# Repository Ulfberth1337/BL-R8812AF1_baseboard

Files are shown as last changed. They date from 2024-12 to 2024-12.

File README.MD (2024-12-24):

This is a baseboard for BL-R8812AF1 WI-FI Module.
USB and Power can be suplied by USB TYPE-C connector or by using TH Pads.
Power requirments are 5V +/- 5% and current 1A.
Baseboard got resetable fuse in order to protect power supply from short circuit and reverse polarity protection.

!!! USE AT OWN RISK !!!

UPD reverse polarity protection part will not work, I mixed up source with drain on mosfet.
The rest of the board works fine.

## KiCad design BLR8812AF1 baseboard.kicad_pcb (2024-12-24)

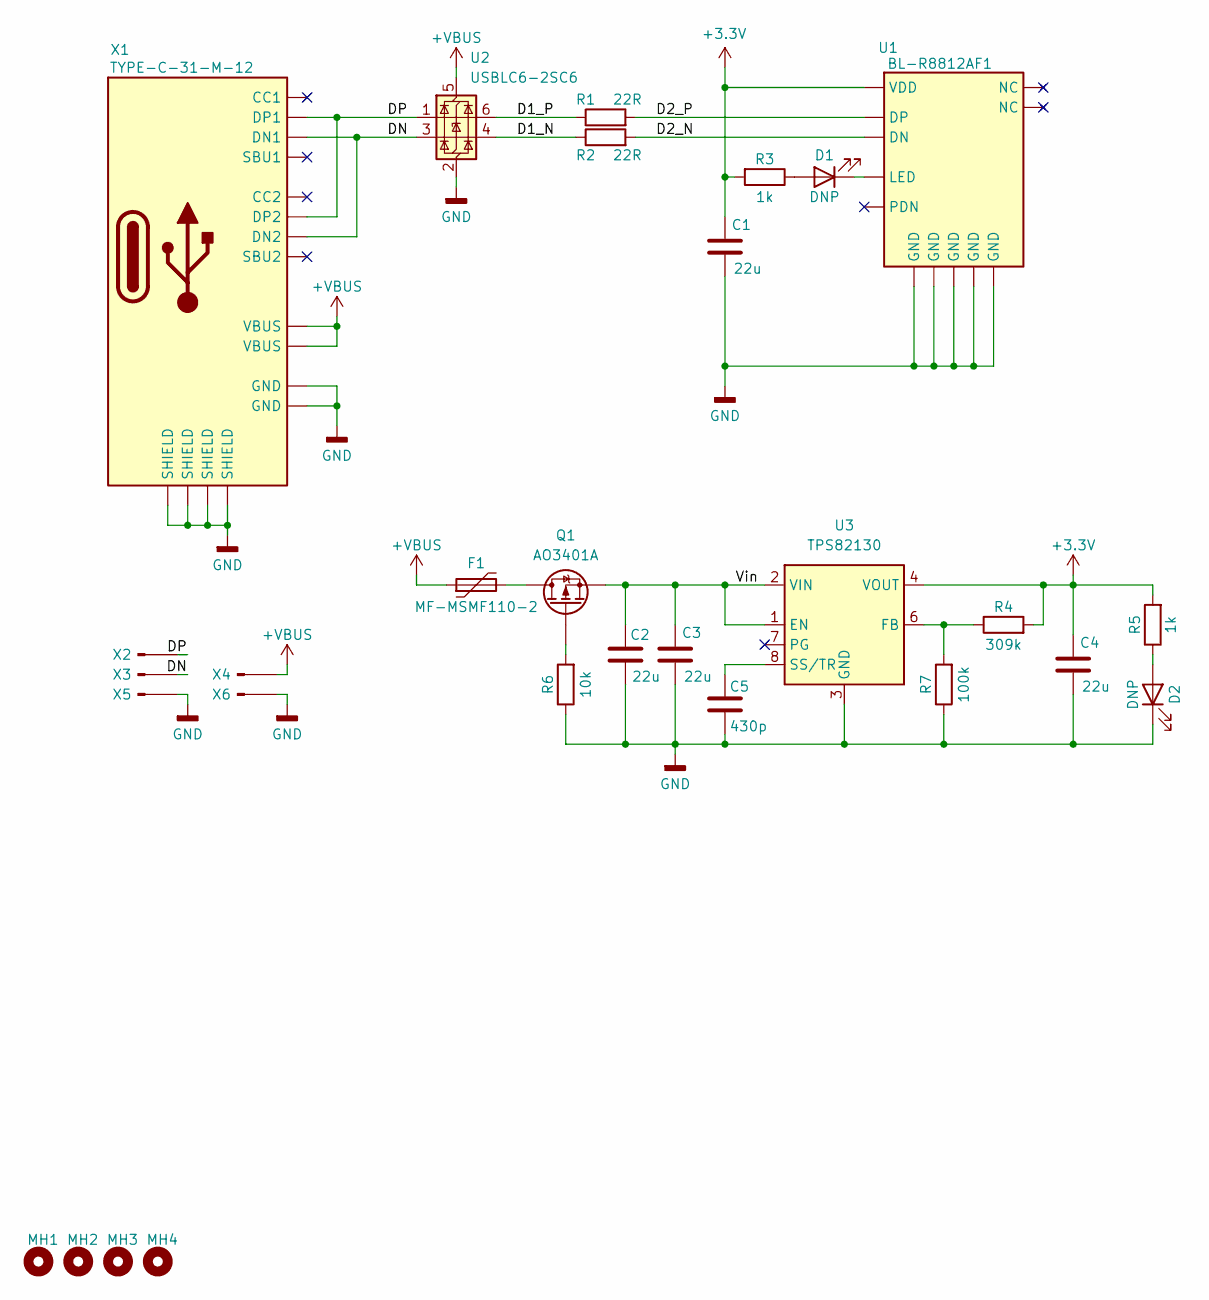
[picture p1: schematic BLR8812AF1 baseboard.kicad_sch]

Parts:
C1, C2, C3, C4: 22u; C_1206_3216Metric
C5: 430p; C_0402_1005Metric
D1, D2: DNP; LED_0603_1608Metric
F1: MF-MSMF110-2; Fuse_1812_4532Metric_Pad1.30x3.40mm_HandSolder
MH1, MH2, MH3, MH4: MountingHole; MountingHole_2.2mm_M2
Q1: AO3401A; SOT-23
R1, R2: 22R; R_0402_1005Metric
R3, R5: 1k; R_0402_1005Metric
R4: 309k; R_0402_1005Metric
R6: 10k; R_0402_1005Metric
R7: 100k; R_0402_1005Metric
U1: BL-R8812AF1
U2: USBLC6-2SC6; SOT-23-6
U3: TPS82130; Texas_SIL0008D_MicroSiP-8-1EP_2.8x3mm_P0.65mm_EP1.1x1.9mm
X1: TYPE-C-31-M-12; HRO-TYPE-C-31-M-12
X2, X3, X5: TH_1_1_0.65
X4, X6: TH_1.7_1.7_1

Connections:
+3.3V: C1.1, C4.1, R3.2, R4.2, R5.2, U1.2 (VDD), U3.4 (VOUT), U3.5 (VOUT)
+VBUS: F1.1, U2.5 (VBUS), X1.A4B9 (VBUS), X1.B4A9 (VBUS), X4.1
/D1_N: R2.1, U2.4 (I/O2)
/D1_P: R1.1, U2.6 (I/O1)
/D2_N: R2.2, U1.3 (DN)
/D2_P: R1.2, U1.4 (DP)
/DN: U2.3 (I/O2), X1.A7 (DN1), X1.B7 (DN2), X3.1
/DP: U2.1 (I/O1), X1.A6 (DP1), X1.B6 (DP2), X2.1
/Vin: C2.1, C3.1, Q1.2 (S), U3.1 (EN), U3.2 (VIN)
GND: C1.2, C2.2, C3.2, C4.2, C5.2, D2.1 (K), R6.1, R7.1, U1.5 (GND), U1.7 (GND), U1.9 (GND), U1.10 (GND), U1.12 (GND), U2.2 (GND), U3.3 (GND), U3.9 (GND), X1.A1B12 (GND), X1.B1A12 (GND), X1.SHIELD, X5.1, X6.1
unnamed: D1.2 (A), R3.1
unnamed: D1.1 (K), U1.6 (LED)
unnamed: D2.2 (A), R5.1
unnamed: F1.2, Q1.3 (D)
unnamed: Q1.1 (G), R6.2
unnamed: R4.1, R7.2, U3.6 (FB)
unnamed: C5.1, U3.8 (SS/TR)

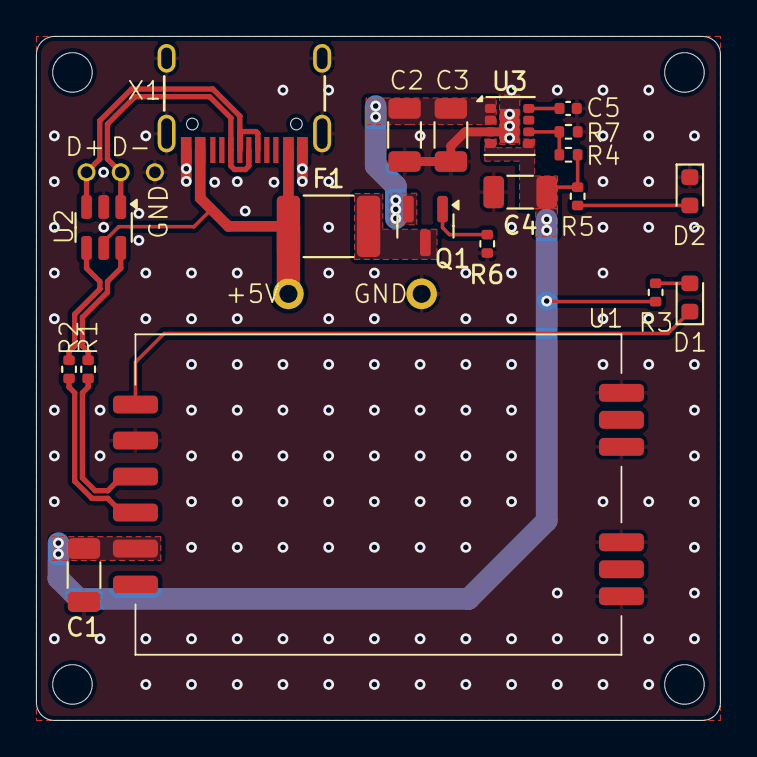
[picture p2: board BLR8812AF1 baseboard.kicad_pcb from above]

Board: 2 copper layers, 38.0 x 38.0 mm, 29 parts (0 on the bottom side), 17 nets.

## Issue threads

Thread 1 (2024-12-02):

transmit RF power

fred-c1, 2024-12-02:
Hello,
Thanks for sharing. Do you know what transmit RF power can be achieve (with “special” linux driver) by this module? My target is 500mW.
Thanks, Fred

Ulfberth1337, 2024-12-03:
Hello, Fred!
First, I want to warn you that I havn't tested this baseboard yet, because I'm still waiting for pcbs.
Also, I'm not sure about how much heat will module produce. If you take a look at my baseboard, iI have removed soldermask underneath it, so one can use thermal paste between module and baseboard and hopefully boards ground plane will be enouth to dissipate heat from module, but again I haven't done any heat calculation for this project.

Now for your question. I'm not sure that this module can provide that much power. The spec says around TX 50mW for each antenna output if I'm not mistaken.
And tuning power with linux drivers is something I haven't tested yet. This is the first time I am using this modules.
They will be used for OpenIPC FPV project. Btw you can try to search for info there. Also I believe there are modules on aliexpress which has PA and LNA build on module, so those might give you the power you want.

Sorry I probably haven't answered your question, but thats all I know :(

So

fred-c1, 2024-12-03:
@Ulfberth1337,
Thanks for your feedback. I am also targeting openIPC. I you find more info later, please post here.
Just FYI, I think that your module is similar to this one:
https://www.aliexpress.com/item/1005006344834608.html
but I haven't been able to identify the 2 PA/LNA chips.
The marking on these chips seems to be SXY21 ???
Thanks!

Ulfberth1337, 2024-12-05:
I'm pretty sure that PA/LNA ICs on that module you provided are [SKY85717-21](https://wmsc.lcsc.com/wmsc/upload/file/pdf/v2/lcsc/2212132130_Skyworks-Solutions-SKY85717-21_C5258861.pdf)
I linked the datasheet,

OpenIPC developing really quick indeed. There are already bunch of modules and stuff. I even saw fully custom FPV module, but it is out of stock now afaik.
I have chosen the RTL8812AU module just because I did not know that there are drivers for EU2 version, otherwise I would bought it, since I don't really need 2.4GHz.

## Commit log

2024-10-19 Working on board
    [BLR8812AF1 baseboard.kicad_pcb, BLR8812AF1 baseboard.kicad_sch]
2024-10-26 Completed placing
    [BLR8812AF1 baseboard.kicad_pcb, BLR8812AF1 baseboard.kicad_sch]
2024-10-28 changed DC-DC
    [BLR8812AF1 baseboard.kicad_pcb, BLR8812AF1 baseboard.kicad_sch]
2024-11-09 almost done
    [BLR8812AF1 baseboard.kicad_pcb, BLR8812AF1 baseboard.kicad_sch]
2024-11-09 Done placing and routing, need to add stiching vias
    [BLR8812AF1 baseboard.kicad_pcb, BLR8812AF1 baseboard.kicad_sch]
2024-11-09 PCB done
    [BLR8812AF1 baseboard.kicad_pcb, BLR8812AF1 baseboard.kicad_sch]
2024-12-24 Fixed reverce voltage protection
    [BLR8812AF1 baseboard.kicad_pcb, BLR8812AF1 baseboard.kicad_sch]
2024-12-24 Fixed PCB and gerber files
    [BLR8812AF1 baseboard-B_Cu.gbr, BLR8812AF1 baseboard-B_Mask.gbr, BLR8812AF1 baseboard-B_Paste.gbr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]
